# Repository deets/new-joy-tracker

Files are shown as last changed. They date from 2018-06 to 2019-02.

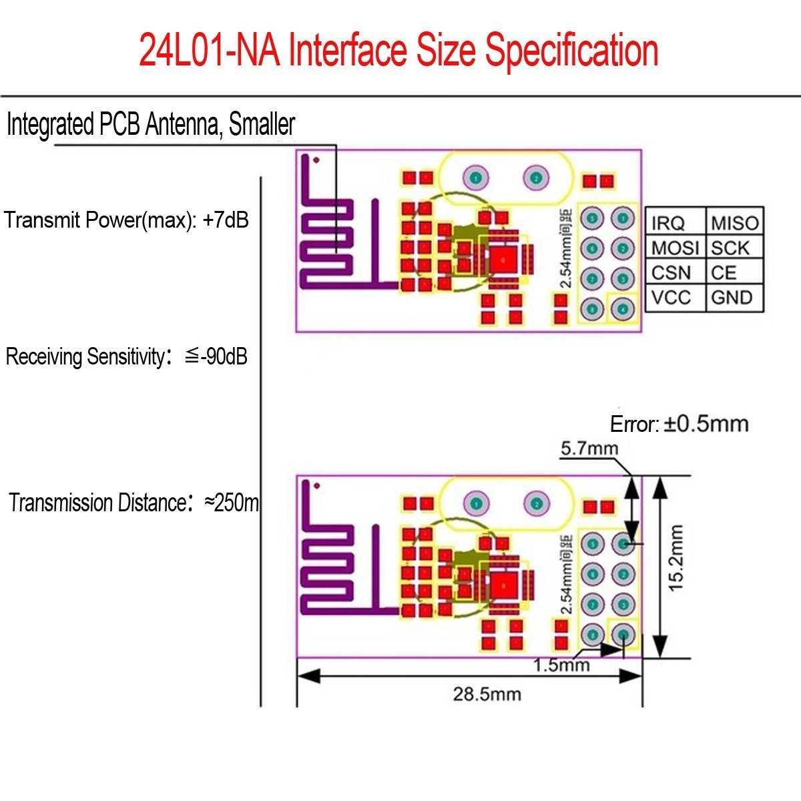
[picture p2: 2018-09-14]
new-joy-board/datasheets/24l01.jpg

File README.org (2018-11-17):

* New Joy Sensor Board

This is documentation for the sensor board I'm developing.

** Sensor Cable Color Coding

I use a 5-wire cable to support the external pressure sensors.

The following table lists the assignment of functions to color:

|--------+----------+---------+--------------|
| Color  | Function | DIN Pin | Sensor Board |
|--------+----------+---------+--------------|
| Black  | GND      |       1 |            1 |
| Brown  | 5V       |       5 |            5 |
| Grey   | 3.3V     |       X |            X |
| Yellow | SDA      |       4 |            4 |
| Blue   | SCL      |       3 |            3 |
|--------+----------+---------+--------------|

** Price Calculation

All calculations are based on a total of 20 Boards.

| Component       | Price per unit |
|-----------------+----------------|
| PCB             |           9.00 |
| ESP32           |          10.00 |
| DC/DC Converter |           4.00 |
|                 |                |

** PCB 

  - https://portal.multi-circuit-boards.eu/
  - [[https://www.amazon.de/gp/product/B0178DX1ZC/ref%3Doh_aui_search_detailpage?ie%3DUTF8&psc%3D1][DC/DC converter]]
  - [[https://www.reichelt.de/OeLFLEX-CLASSIC/CL100-5G0-5-50/3/index.html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][5 wire cable]]
  - [[https://e2e.ti.com/support/interface/i2c/f/390/t/615703?P82B715-Not-reading#][P82B715 setup example]]
  - [[http://www.mathertel.de/Arduino/DMXShield.aspx][Good explanation of DMX transmitter setup]]
  - [[https://www.youtube.com/watch?v%3D8NDq6hC9KJo][ESP32 power consumption assessment]]
  - [[https://github.com/clacktronics/pyb_dmx/blob/master/dmx.py][Crappy but useful uPy implementation of DMX]]
  - [[https://de.wikipedia.org/wiki/DMX_(Lichttechnik)][DMX connector assignment]]
  - [[https://www.element14.com/community/groups/open-source-hardware/blog/2017/08/24/dmx-explained-dmx512-and-rs-485-protocol-detail-for-lighting-applications][Nice DMX512 intro]]
  - [[https://www.reichelt.de/PT15-Pihertrimmer-15mm/PT-15-L-10K/3/index.html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][Trimm-Poti 10K]]
  - [[https://www.reichelt.de/Elkos-SMD-Low-ESR-105-C/SMD-ELKO-10-35/3/index.html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][SMD Elko]]

*** Pull up calculation

According to the P82B715 datasheet we need to calculate the pullups for the buffered bus as follows:

#+BEGIN_QUOTE
R = 1 μs/(C_device + C_wiring)

where

 - C_device = Sum of any connected device capacitances
 - C_wiring = Total wiring and stray capacitance on the bus section 

If these capacitances cannot be measured or calculated, an
approximation can be made by assuming that each device presents 10 pF
of load capacitance and 10 pF of trace capacitance, and that cables
range from 50 pF to 100 pF per meter.
#+END_QUOTE
 
For our use-case with up to 4 devices connected, the calculation should be

4 devices connected with a meter cable each:

20pF * 4 + (100pF * 4) = 500pF -> 0.000001 / (0.000000000500) = 2KOhm

** ESP32

*** Physical

*** Useful links

 - [[http://esp32.net/#Hardware][Overview of boards from espressif themselves]]
 - [[http://playground.arduino.cc/Main/MPU-6050][MPU6050 programming with the Arduino]]
 - [[https://github.com/kriswiner/ESP32/blob/master/MPU9250_MS5637/MPU9250_MS5637_AHRS.ino][ESP32 IMU Sensor Fusion Project]]
 - [[https://www.adafruit.com/product/439][I2C Light (visible/IR) Sensor ]]
 - [[https://github.com/nkolban/esp32-snippets][ESP32 native SDK snippets]]

*** References

bme280 code pilfered from

  https://github.com/catdog2/mpy_bme280_esp8266

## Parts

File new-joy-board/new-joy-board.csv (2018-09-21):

Reference | Quantity | Value | Footprint | Datasheet | Field4
C1 C2 C3 C4 | 4 | 0.1uF | Capacitor_SMD:C_0805_2012Metric_Pad1.15x1.40mm_HandSolder | ~ | 399-1169-1-ND
C5 C6 C7 C8 | 4 | 47uF | Capacitor_SMD:CP_Elec_5x5.8 | ~ | PCE3890CT-ND
J0 J1 J2 J3 | 4 | SDS-50J | new-joy:CUI_SDS-50J | CUI Inc | CP-2350-ND
J4 | 1 | BAT | TerminalBlock:TerminalBlock_bornier-2_P5.08mm |  | ED2609-ND
R1 R10 R11 R12 R13 R14 R15 R16 R2 R3 R4 R5 R6 R7 R8 R9 | 16 | 2K2 | Resistor_SMD:R_0805_2012Metric_Pad1.15x1.40mm_HandSolder |  | RNCP0805FTD2K21CT-ND
U10 | 1 | oskj-dc-dc | new-joy:oskj-dc-dc
U0 U1 U2 U3 | 4 | P82B715 | new-joy:P82B715D |  | 296-24729-1-ND
U4 | 1 | AZReady_ESP32 | new-joy:AZReady_ESP32
U5 | 1 | 24L01 | new-joy:24L01
U7 | 1 | MPU6050_Breakout | new-joy:MPU6050_Breakout

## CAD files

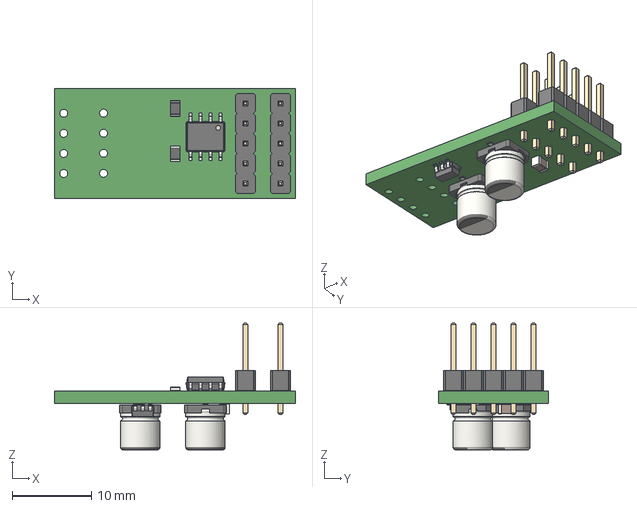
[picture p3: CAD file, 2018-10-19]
new-joy-board/bmp280-sensor-board/bmp280-sensor-board.step
30.5 x 14.0 x 16.0 mm

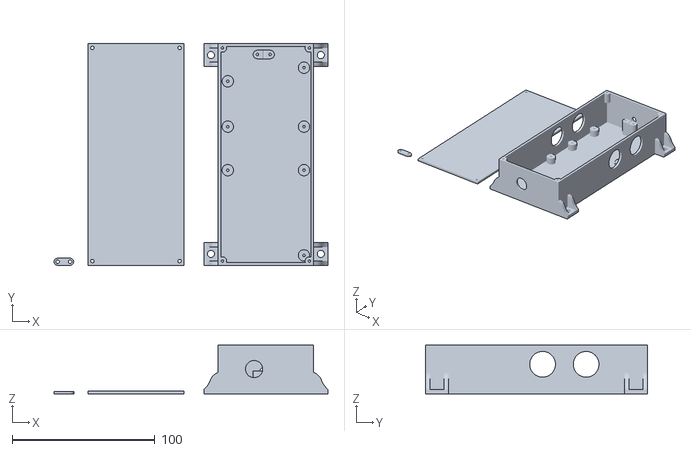
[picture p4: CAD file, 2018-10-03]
new-joy-board/nj-baseboard.stl
191.9 x 155.2 x 34.0

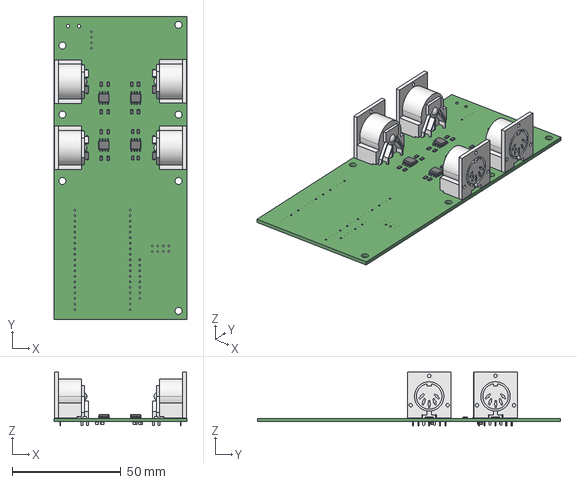
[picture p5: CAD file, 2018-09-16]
new-joy-board/new-joy-board.step
61.0 x 139.2 x 24.6 mm

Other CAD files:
new-joy-board/new_joy_board.FCStd

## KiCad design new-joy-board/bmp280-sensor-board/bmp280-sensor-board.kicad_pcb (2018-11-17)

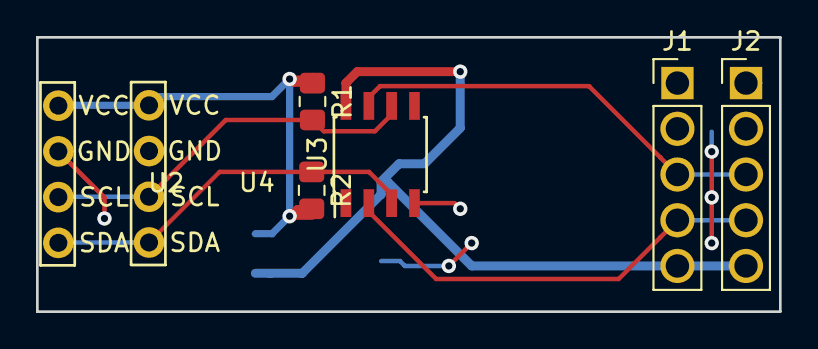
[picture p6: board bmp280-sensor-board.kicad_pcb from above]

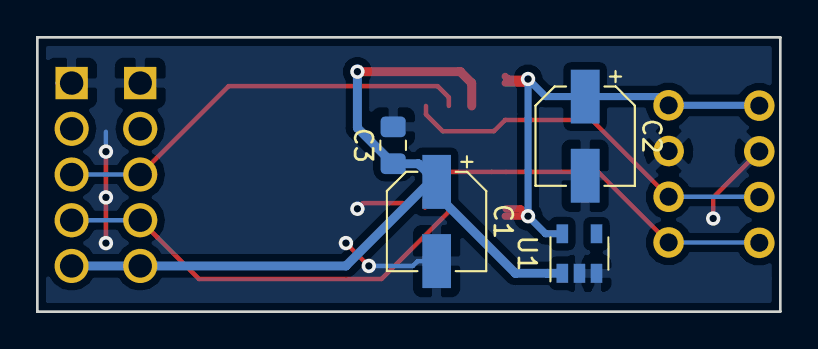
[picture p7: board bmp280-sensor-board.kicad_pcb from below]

Board: 2 copper layers, 41.3 x 15.2 mm, 11 parts (4 on the bottom side), 7 nets.

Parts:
C1, C2: 47uF; CP_Elec_5x5.8
C3: 0.1uF; C_0805_2012Metric_Pad1.15x1.40mm_HandSolder
J1, J2: Conn_01x05; Buffered-I2C-Cable-Connector
R1, R2: 2K2; R_0805_2012Metric_Pad1.15x1.40mm_HandSolder
U1: TPS76933; SOT-23-5
U2, U4: generic-i2c-device
U3: P82B715; P82B715D

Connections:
+3V3: C2.1, R1.1, R2.2, U1.5, U2.1, U4.1
+5V: C1.1, C3.1, J1.5, J2.5, U1.1, U3.8
/SCL: R1.2, U2.3, U3.6, U4.3
/SCLBUF: J1.3, J2.3, U3.7
/SDA: R2.1, U2.4, U3.3, U4.4
/SDABUF: J1.4, J2.4, U3.2
GND: C1.2, C2.2, C3.2, J1.1, J2.1, U1.2, U1.3, U2.2, U3.4, U4.2

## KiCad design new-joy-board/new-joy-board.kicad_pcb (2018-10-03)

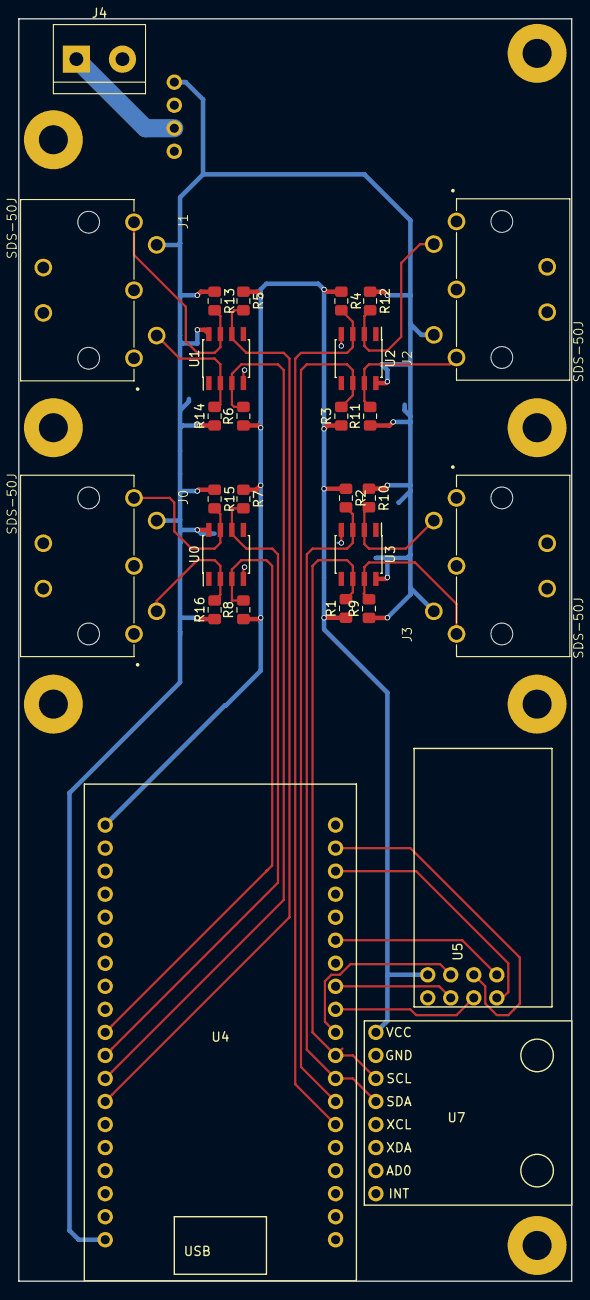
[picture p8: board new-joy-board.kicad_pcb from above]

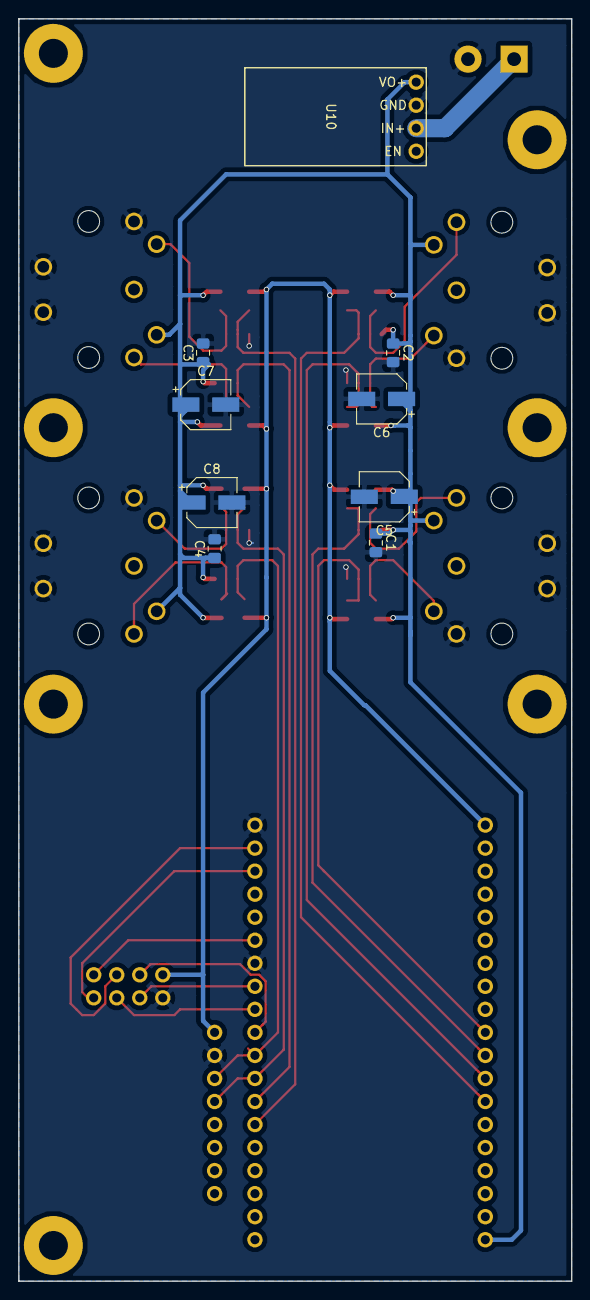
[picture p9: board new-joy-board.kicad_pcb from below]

Board: 2 copper layers, 61.0 x 139.2 mm, 37 parts (9 on the bottom side), 26 nets.

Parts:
C1, C2, C3, C4: 0.1uF; C_0805_2012Metric_Pad1.15x1.40mm_HandSolder
C5, C6, C7, C8: 47uF; CP_Elec_5x5.8
J0, J1, J2, J3: SDS-50J; CUI_SDS-50J
J4: BAT; TerminalBlock_bornier-2_P5.08mm
R1, R2, R3, R4, R5, R6, R7, R8, R9, R10, R11, R12, R13, R14, R15, R16: 2K2; R_0805_2012Metric_Pad1.15x1.40mm_HandSolder
U0, U1, U2, U3: P82B715; P82B715D
U4: AZReady_ESP32
U5: 24L01
U7: MPU6050_Breakout
U10: oskj-dc-dc

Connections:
+3V3: R1.1, R2.1, R3.1, R4.1, R5.1, R6.1, R7.1, R8.1, U4.1, U5.8, U7.1
+5V: C1.1, C2.1, C3.1, C4.1, C5.1, C6.1, C7.1, C8.1, J0.5, J1.5, J2.5, J3.5, R9.1, R10.1, R11.1, R12.1, R13.1, R14.1, R15.1, R16.1, U0.8, U1.8, U2.8, U3.8, U4.19, U10.1
+BATT: J4.1, U10.3
-BATT: C1.2, C2.2, C3.2, C4.2, C5.2, C6.2, C7.2, C8.2, J0.1, J0.S1, J0.S2, J1.1, J1.S1, J1.S2, J2.1, J2.S1, J2.S2, J3.1, J3.S1, J3.S2, J4.2, U0.4, U1.4, U2.4, U3.4, U4.32, U4.38, U5.4, U7.2, U10.2
/CE: U4.31, U5.3
/CLK: U4.30, U5.2
/CS0: U4.29, U5.7
/IRQ: U4.33, U5.5
/MISO: U4.36, U5.1
/MOSI: U4.37, U5.6
/SCL0BUF: J0.3, R15.2, U0.7
/SCL0ESP: R7.2, U0.6, U4.11
/SCL1BUF: J1.3, R13.2, U1.7
/SCL1ESP: R5.2, U1.6, U4.13
/SCL2BUF: J2.3, R11.2, U2.7
/SCL2ESP: R3.2, U2.6, U4.26
/SCL3BUF: J3.3, R9.2, U3.7
/SCL3ESP: R1.2, U3.6, U4.28, U7.3
/SDA0BUF: J0.4, R16.2, U0.2
/SDA0ESP: R8.2, U0.3, U4.10
/SDA1BUF: J1.4, R14.2, U1.2
/SDA1ESP: R6.2, U1.3, U4.12
/SDA2BUF: J2.4, R12.2, U2.2
/SDA2ESP: R4.2, U2.3, U4.25
/SDA3BUF: J3.4, R10.2, U3.2
/SDA3ESP: R2.2, U3.3, U4.27, U7.4

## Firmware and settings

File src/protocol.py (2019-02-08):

# -*- coding: utf-8 -*-
# Copyright: 2018, Diez B. Roggisch, Berlin . All rights reserved.
import ustruct
import newjoy
import utime
import machine
import debugpin
from names import MAPPING


class Protocol:

    TASK_SPEC = {
        newjoy.TASK_MPU6050: "ffffff",
        newjoy.TASK_BMP280: "I",
    }

    TASK_ID = {
        newjoy.TASK_MPU6050: "i",
        newjoy.TASK_BMP280: "p",
    }

    def __init__(self):
        self._tasks = []
        self.buffer = None
        self.payload = None
        self._osc_spec = []
        self._osc_payload_start = -1
        uid = machine.unique_id()
        if uid in MAPPING:
            self._osc_path = "/" + MAPPING[uid]
        else:
            self._osc_path = "/" + "".join(
                [hex(c)[2:] for c in uid]
            )
        self._osc_descriptor = {
            0: "",
            1: "",
            2: "",
            3: "",
        }
        self._mask = 0

    def register_task(self, bus, address, task, buffer_size, busno):
        self._tasks.append((bus, address, task, buffer_size, busno))

    def assemble(self, sensor_period):
        name = machine.unique_id()
        assert len(name) == 6
        task_num = len(self._tasks)
        # we have a start-character, '#'
        start_char = 1
        # after that start character, we follow up with the of the
        # total message.  It's the length in one byte, followd by the
        # XOR of that length.  The reason for this verified storage is
        # that we need a reliable way of syncing after the start-char
        # to the expected number of bytes
        message_length = 2
        # Then comes the unique ID of the device, 6 bytes
        name_length = len(name)
        # After that, the task count and descriptor. The descriptor specifies
        # the attached sensors/tasks, that all have a specific byte-size.
        # Each sensor is described as a nibble, with the first in the lowest
        # nibble of the first byte, second upper nibble, etc.
        task_count = 1
        descriptor_length = task_num // 2 + task_num % 2
        # it follows the payload, the size is the accumulated size of
        # all tasks' storage needs
        payload_size = sum(
            buffer_size for _, _, _, buffer_size, _
            in self._tasks
        )
        # the final checksum is just all bytes so far summed up as uint8_t
        checksum_size = 1
        buffer_size = start_char + message_length + name_length + \
          task_count + descriptor_length + \
          payload_size + checksum_size

        name_start = start_char + message_length
        descriptor_byte_count_offset = start_char + \
            message_length + name_length
        descriptor_start = descriptor_byte_count_offset + task_count
        payload_start = descriptor_start + descriptor_length
        if payload_start % 4:
            padding = 4 - (payload_start % 4)
            payload_start += padding
            buffer_size += padding
        self.buffer = bytearray(buffer_size)
        self.buffer[0] = ord(b'#')
        self.buffer[1] = buffer_size
        self.buffer[2] = 0xff ^ buffer_size
        self.buffer[name_start:name_start + name_length] = name
        self.buffer[descriptor_byte_count_offset] = task_num

        descriptor = memoryview(self.buffer)[
            descriptor_start:descriptor_start+descriptor_length
        ]
        newjoy.init(sensor_period, self.buffer)
        osc_payload_start = task_byte_offset = payload_start

        for i, (bus, address, task, task_size, busno) in enumerate(self._tasks):
            self._osc_spec.append(
                (
                    osc_payload_start,
                    self.TASK_SPEC[task],
                )
            )
            self._osc_descriptor[busno] += self.TASK_ID[task]
            offset = i // 2
            current = descriptor[offset]
            current |= task << (4 * (i % 2))
            descriptor[offset] = current
            newjoy.add_task(bus, address, task, task_byte_offset)
            task_byte_offset += task_size
            osc_payload_start += task_size

        osc_descriptor = ""
        for busno, devices in sorted(self._osc_descriptor.items()):
            if devices:
                osc_descriptor += "{}{}".format(busno, devices)
        self._osc_descriptor = osc_descriptor

    def update(self):
        newjoy.sync()

    def send_osc(self, osc):
        for i, (osc_payload_start, spec) in enumerate(self._osc_spec):
            if 1 << i & self._mask:
                continue
            args = ustruct.unpack_from(
                spec,
                self.buffer,
                osc_payload_start,
            )
            # this is butt-ugly, but the setup.CONNECT_TO_NET
            # controls if osc is None or not. And with this
            # hack the debugpin prints something even if there
            # is no network
            if osc is not None:
                osc.send(self._osc_path, i, utime.ticks_ms(), *args)
            if debugpin.DEBUG_MODE:
                print(i, args)

    def process_incoming(self, message):
        if message[0] == ord(b"R"):
            machine.reset()
        elif message[0] == ord(b"M"):
            mask = message[1]
            if debugpin.DEBUG_MODE:
                print('updating mask to', mask)
            self._mask = mask
        elif message[0] == ord(b"G"):
            sensor_no, gain = ustruct.unpack("<Bf", message[1:])
            newjoy.set_task_parameters(sensor_no, ustruct.pack("<f", gain))

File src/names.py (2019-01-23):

# This is taken from the name.db and
# needs updating once we observe new
# boards!
import machine

MAPPING = {
    b'0\xae\xa4{\xcc\xe4': 'LANA',
    b'0\xae\xa4{\xcd\x00': 'ANNE',
    b'0\xae\xa4\x84z\xd0': 'BERT',
    b'0\xae\xa4\x8b\x8d\xf4': 'YVES',
    b'0\xae\xa4\x8b\xd9\xe0': 'IRIS',
    b'\xb4\xe6-\x94[]': 'PAUL',
    b'\xb4\xe6-\x96"-': 'NILS',
    b'\xb4\xe6-\x963\xc1': 'JANA',
    b'\xb4\xe6-\x966\x15': 'DANA',
    b'\xb4\xe6-\xb22\xb5': 'GINA',
    b'\xb4\xe6-\xbfB\xa1': 'WOUT',
    b'\xb4\xe6-\xbf\xda\xb5': 'OTTO',
    b'0\xae\xa4}d\xd4': 'RALF',
}


def get_name():
    return MAPPING[machine.unique_id()]


def get_pipe_id(name=None):
    if name is None:
        id_ = machine.unique_id()
    else:
        for key, value in MAPPING.items():
            if value == name:
                id_ = key
                break
        else:
            raise Exception("No id for name {} found".format(name))

    return id_[:5]

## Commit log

2018-06-15 Begin work on ESP and other component library
    [new-joy-board.kicad_pcb, new-joy-board.sch]
2018-06-15 First iteration footprint
2018-06-16 Associate footprints and adjust pads for library
2018-06-16 3V3 power regulator and i2c0 bus
    [new-joy-board.kicad_pcb, new-joy-board.sch]
2018-06-16 Add MPU6050 breakout board schematic and footprint
2018-06-17 Add P82B715 I2C extender to library
2018-06-17 Add concrete component links and I2C bus impedance calculation
2018-06-17 Worked on design, including DMX and buffered I2C
    [new-joy-board.kicad_pcb, new-joy-board.sch]
2018-07-29 Remove superfluous socket option
2018-07-29 define I2C bus cable coloring
2018-08-18 Concept sketch for my PCB I2C bus driver mockup
2018-08-18 Send IMU data and introduce async server to receive it
2018-08-18 Read both gyro and barometer and send both over with protocol
2018-08-21 Add small visualisation prototype
2018-08-21 Send gyro x, and visualise it
2018-08-21 Send all IMU data
2018-08-22 Interesting link for IMU procssing with the ESP32
2018-08-22 Interesting link for a light sensor
2018-08-25 Add DIN connector with 3d representation
2018-08-25 Add footprint for 3mm drill-hole to mount pcb
2018-08-25 Work on schematic and PCB to mock up real PCB
    [new-joy-board.kicad_pcb, new-joy-board.sch]
2018-08-26 More PCB work to determine final dimensions for case construction
    [new-joy-board-2018-08-24-15-09-01.sch, new-joy-board.kicad_pcb, new-joy-board.sch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]
2018-09-02 Determine 4 pin-combinations for I2C interfaces
2018-09-02 Interesting ESP32 link added to docs
2018-09-02 Reworked id system as macs aren't working
    [protocol.py]
2018-09-07 Wired up 3 more boards and assigned names
2018-09-09 Routet half of the I2C buffers
    [new-joy-board.kicad_pcb, new-joy-board.sch]
2018-09-09 First draft of full layout
    [new-joy-board.kicad_pcb, new-joy-board.sch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]
2018-09-14 Start rework to slimmer design, and add capacitors to I2C drivers
    [new-joy-board.csv, new-joy-board.kicad_pcb, new-joy-board.sch]
2018-09-14 Add NRF24 board to library
2018-09-14 Route new board layout
    [new-joy-board.kicad_pcb, new-joy-board.sch]
2018-09-16 Designed in the 24L01 board for emergency use
    [new-joy-board.kicad_pcb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]
2018-09-16 Replaced the 1uF with 47uF Elekos as per David's recommendation
    [new-joy-board.kicad_pcb, new-joy-board.sch]
2018-09-21 Generated manufacturing files and ordered PCB
    [_saved_new-joy-board.sch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]
2018-09-21 The current revision of the 3D-printed case
    [nj-mainboard.stl]
2018-09-22 Added the missing solder mask layers
    [_saved_new-joy-board.sch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]
2018-10-03 Use newjoy module to drive sensors
2018-10-03 Add BMP280 breakout board to schema and footprint libs
    [bmp280-sensor-board.kicad_pcb, bmp280-sensor-board.sch]
2018-10-03 Fix pads for through-the-hole boards
2018-10-03 Exchanged new footprints with bigger pads in the boards
    [new-joy-board.kicad_pcb]
2018-10-03 Datasheets for pressure sensor and LDO
2018-10-03 New version of case with bigger screw holes
    [nj-baseboard.stl, nj-mainboard.stl]
2018-10-03 Added mounting-holes
    [bmp280-sensor-board.kicad_pcb]
2018-10-03 Placed MPU6050 as additional option
    [bmp280-sensor-board.sch]
2018-10-03 New version of base board pcb with bigger holes
    [new-joy-board-B.Cu.gbr, new-joy-board-B.Mask.gbr, new-joy-board-B.SilkS.gbr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]
2018-10-03 Removed superfluous subdirectory
    [bmp280-sensor-board.kicad_pcb, bmp280-sensor-board.sch, bmp280-sensor-board.step]
2018-10-03 Add labels to bmp footprint
2018-10-03 Add generic I2C device footprint
2018-10-19 Continue work on daughter board
    [bmp280-sensor-board.kicad_pcb, bmp280-sensor-board.sch, bmp280-sensor-board.step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]
2018-11-17 Add DIN pin mapping to cable description
2018-11-17 Prolonged daughter board and added footprint for better soldering
    [bmp280-sensor-board.kicad_pcb, bmp280-sensor-board.sch]
2018-11-17 Resized board to conform with multi cb
    [bmp280-sensor-board-B.Cu.gbr, bmp280-sensor-board-B.Mask.gbr, bmp280-sensor-board-B.SilkS.gbr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]
2018-11-17 Sensor Board cable documentation
2018-11-17 Correct I2C port setup
2018-11-17 Parse descriptor correctly and create full data
    [protocol.py]
2018-11-18 Directly send OSC messages from the devices
2018-12-08 Remove superflous and confusing print statement
2018-12-19 Added test-programs for nrf24l01
    The system works. Wooooot!
    Taken from https://github.com/micropython/micropython/tree/master/drivers/nrf24l01
2019-01-18 Remove BMP sensors as we don't use them right now
2019-01-21 Add debug-pin functionality
2019-01-21 Fix osc offset bug
    [protocol.py]
2019-01-22 Make joining network chosable, debugpin prints task-info
2019-01-22 Debug-pin is not on by default, newjoy.max_task_time added
2019-01-22 Enhance debug-pin behaviour, but turn it off by default
2019-01-24 Update plot by angles to show-case this updating
2019-02-08 Replaced cylinder with coordinate root
2019-02-08 Name the gizmos with board/sensor-no
2019-02-08 We have a working reset button
2019-02-08 Listen to incoming messages, and process R for reset
    [protocol.py]
2019-02-08 Implement masking of sensor sending, and more robust connection code
